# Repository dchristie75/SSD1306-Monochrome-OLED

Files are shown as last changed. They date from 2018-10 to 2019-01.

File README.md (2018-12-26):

# SSD1306 Monochrome OLED

## Build Instructions for Broadcom Devepolment Platform (Raspberry Pi 3B+) and SSD1306 OLED Display

### Table of Contents
1.  [Introduction](#introduction)
2.  [Bill of Materials](#bill-of-materials) 
3.  [Time Commitment](#time-commitment)
4.  [Mechanical Assembly](#mechanical-assembly)
5.  [PCB/Soldering](#pcb-soldering)
6.  [Power Up](#power-up)
7.  [Unit Testing](#unit-testing)
8.  [Production Testing](#production-testing)
9.  [Reproducible](#reproducible)

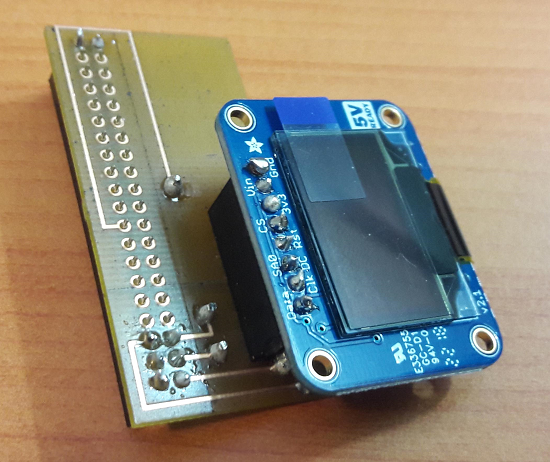
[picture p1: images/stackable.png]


### Introduction
The aim of this project is to integrate a sensor/effector with the Broadcom development platform, also known as the Raspberry Pi, in order to read/write data to the device. The sensor/effector chosen for this project is the SSD1306 OLED Monochrome Display from Adafruit. It is a 1" diagonal display that is made of 128x64 individual white OLED pixels that uses both SPI and I2C interfaces. Over the course of fifteen weeks, few necessary documentations were created, including the project proposal, a project breakdown schedule, and budget for the project. The necessary hardware components were also acquired, along with the required components to put everything together. A wiring circuit diagram was developed in [Fritzing](http://fritzing.org/home/) and was used to breadboard and test the sensor with the Broadcom development platform. Using that prototype, a custom PCB was designed and sent to the Prototype lab for etching. Headers were then soldered to the PCB for stacking and final assembly. The image above demonstrate the final stackable interface for the project. 

### Bill of Materials
To embark on the project, the necessary parts and components will need to acquired. Displayed below is the budget of the price breakdown for components used in the project. The spreadsheet version of the budget with links to the sources for the components can be found [here](https://github.com/dchristie75/SSD1306-Monochrome-OLED/blob/master/Documentation/Hardware_Production_Budget.xlsx).

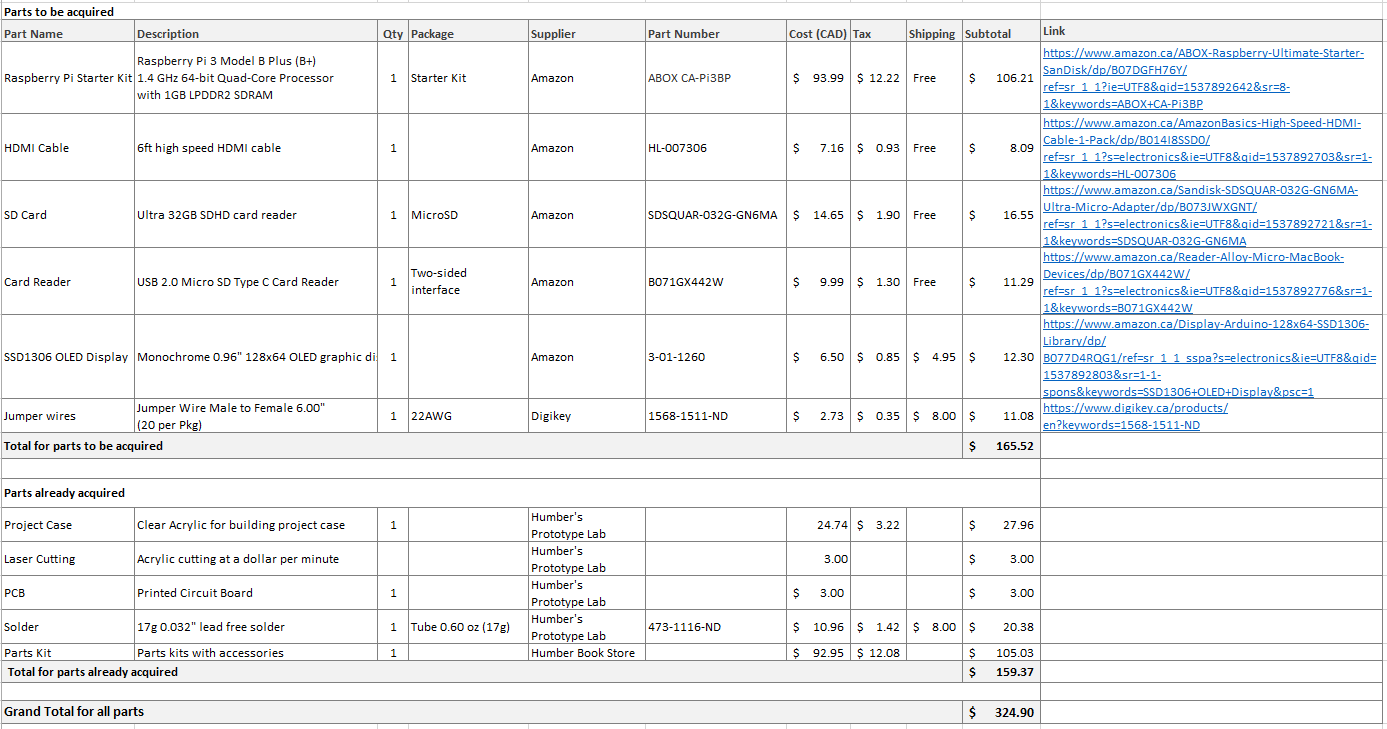
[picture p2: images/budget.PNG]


#### Listed below are some of the major components used in the project
SSD1306 OLED Monochrome 128x64 Display<br/>
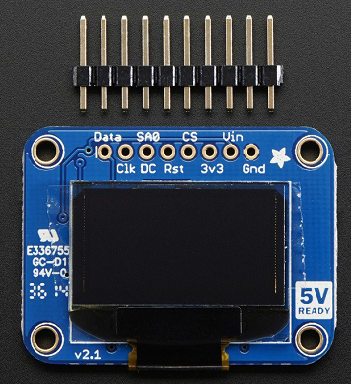
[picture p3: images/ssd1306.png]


Raspberry Pi Kit<br/>
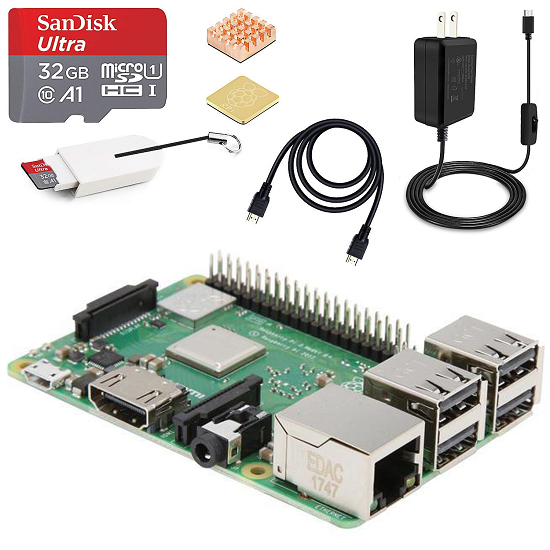
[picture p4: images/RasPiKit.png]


Components kit with stackable headers<br/>
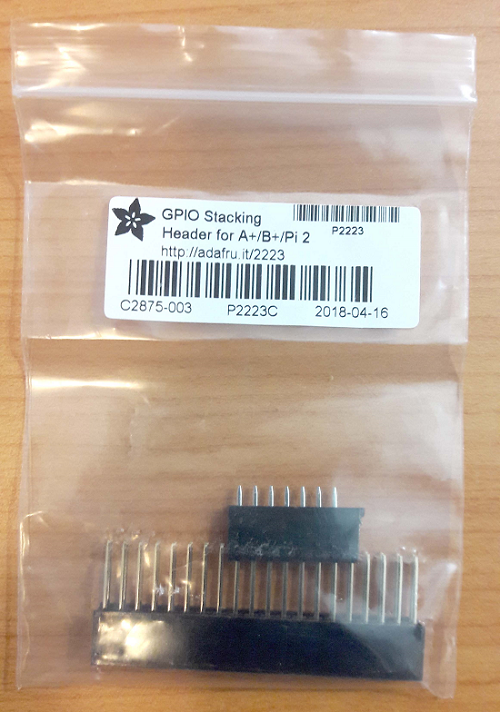
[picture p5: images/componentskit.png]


### Time Commitment
The entire project was done over the course of fifteen weeks, starting from selecting the OLED on September 4 to submitting the Build Instructions on December 11, 2018. However, to realistically build the project, a person could potentially use a weekend to complete it, assuming he has all the necessary components. Below is a breakdown of the project schedule.

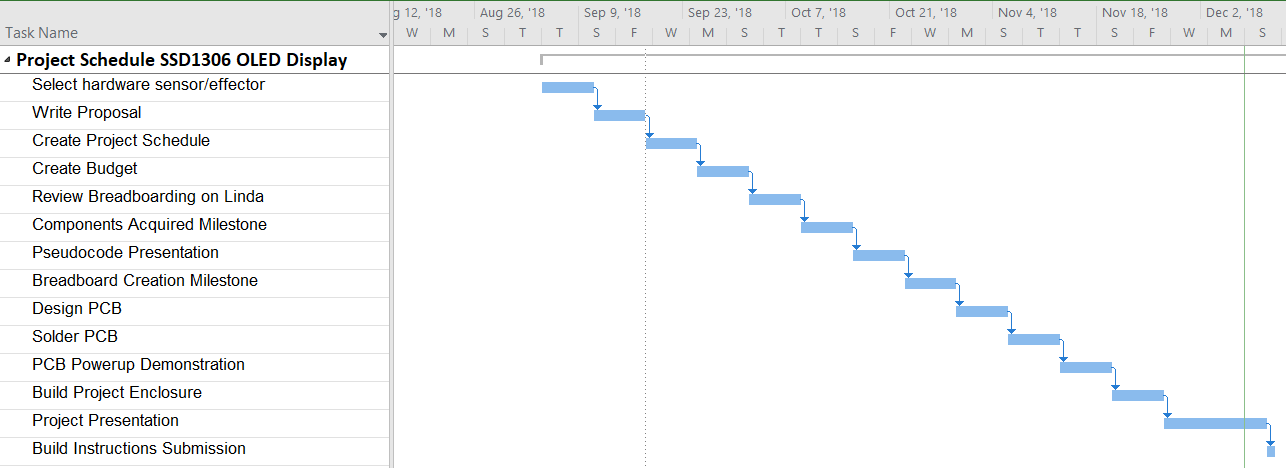
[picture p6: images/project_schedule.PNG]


### Mechanical Assembly
This step involves putting everything together. Hence, ensure the [8 pin header strip](https://github.com/dchristie75/SSD1306-Monochrome-OLED/blob/master/images/ssd1306.png) that comes with the OLED display is securely soldered to the device. Ensure the [PCB](https://github.com/dchristie75/SSD1306-Monochrome-OLED/blob/master/images/pcb.png) is designed in [Fritzing](http://fritzing.org/home/) and etched at the Prototype lab. Also, ensure the component [headers](https://github.com/dchristie75/SSD1306-Monochrome-OLED/blob/master/images/componentskit.png) are soldered onto the PCB. The enclosure should also be designed in [CorelDraw](https://www.coreldraw.com/en/product/coreldraw/?topNav=en) and sent to the Prototype lab for lazer cutting. The final CorelDraw design for the enclosure can be found [here](https://github.com/dchristie75/SSD1306-Monochrome-OLED/blob/master/Documentation/Pi2Case.cdr). After gathering all these components, now we are ready to assemble. Here are the steps involved: 

1. Mount the SSD1306 display to the PCB to create a stackable header<br/> 


2. Mount the stackable header to the Broadcom development platform GPIO port<br/>
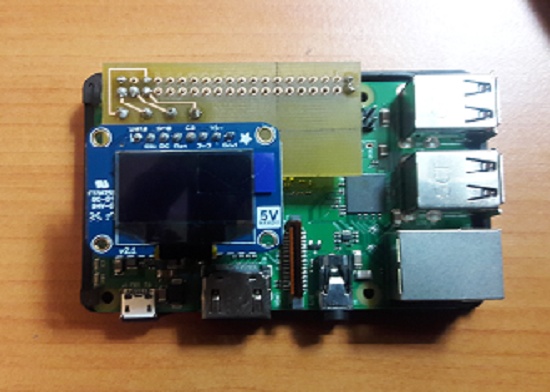
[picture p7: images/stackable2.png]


3. Install the Broadcom development platform with the stackable header in Acrylic enclosure<br/>
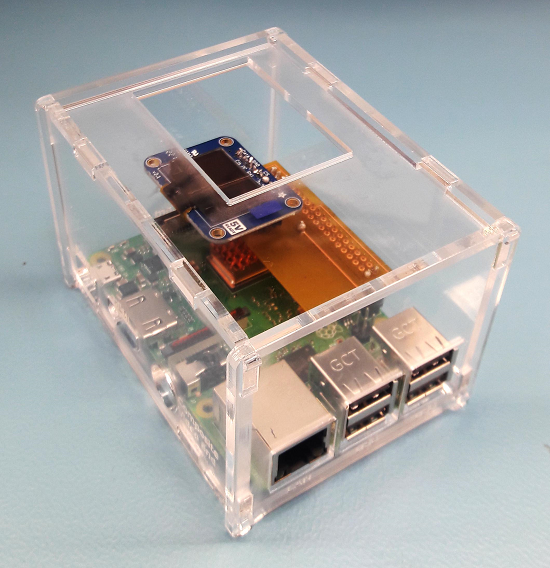
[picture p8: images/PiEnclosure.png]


### PCB Soldering
Soldering the components will take a little effort especially if you have never soldered before. Some good lesson on soldering can be found [here](https://www.youtube.com/watch?v=oqV2xU1fee8). Here are the steps in soldering all the components for the project:

1. Solder the two jumpers on the back of the OLED. Both must be soldered 'closed' for the I2C interface to work.

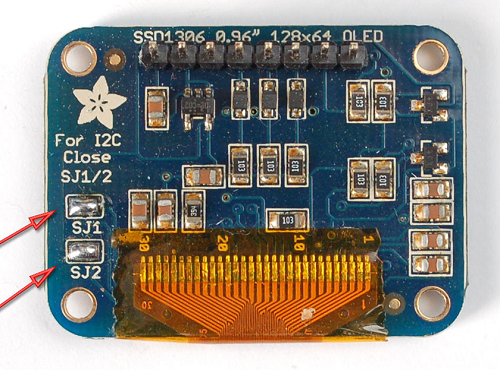
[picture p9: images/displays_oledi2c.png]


2. Solder the 8 pin header to the OLED display.

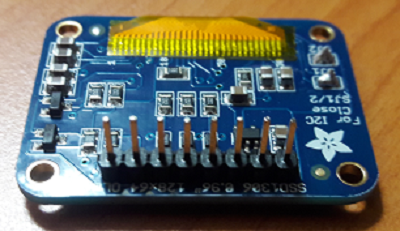
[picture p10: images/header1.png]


3. Design the initial breadboard layout for the PCB in Fritzing

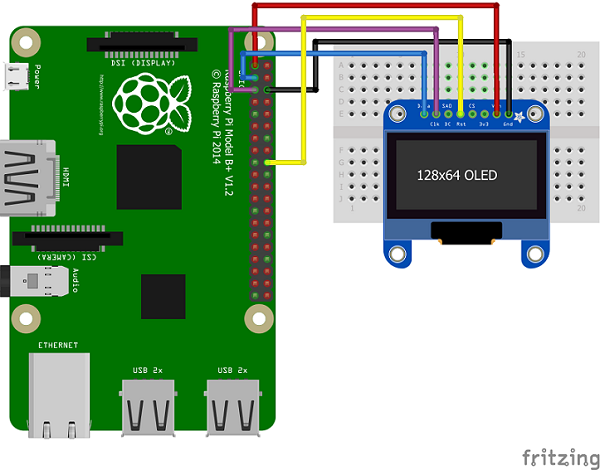
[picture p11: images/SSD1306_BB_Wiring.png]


4. The breadboard design layout will automatically generate a schematic diagram for the PCB design 

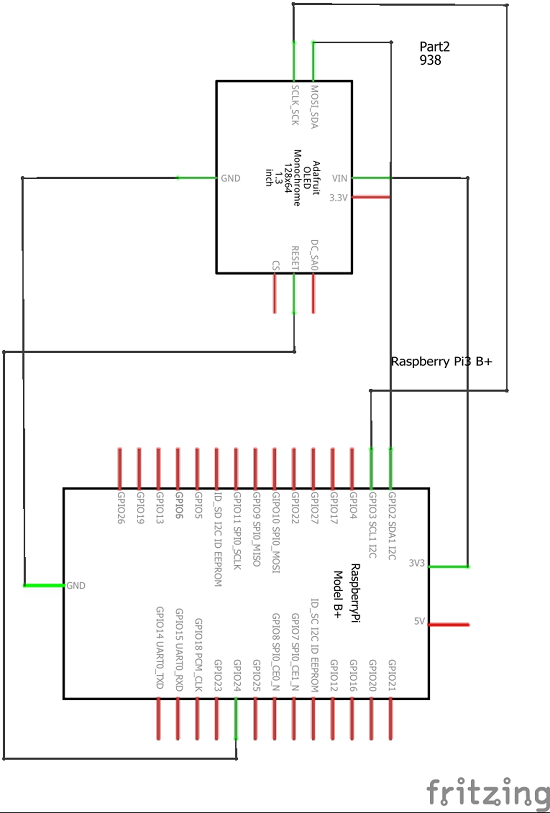
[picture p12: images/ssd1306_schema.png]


5. From the initial breadboard wiring design and resulting schema, design the actual PCB layout in Fritzing to send to production 

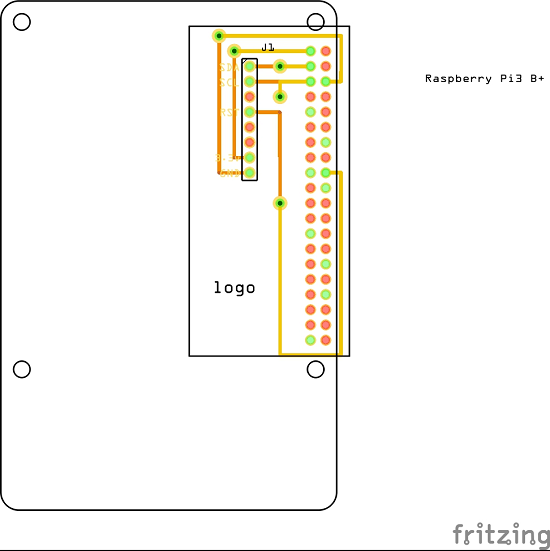
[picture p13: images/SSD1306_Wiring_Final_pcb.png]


6. Image of the resulting etched PCB after production 

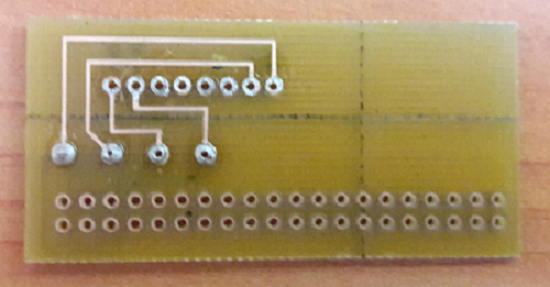
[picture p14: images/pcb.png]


7. Below is an image of the headers soldered to the PCB with OLED display mounted

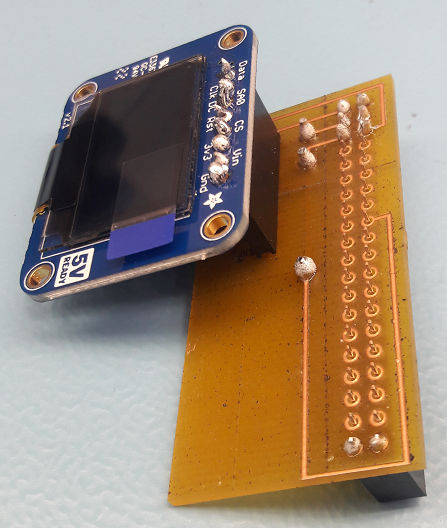
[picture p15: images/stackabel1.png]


 8. Below is the stackable header mounting to the Broadcom development platform



### Power Up
After connecting the OLED display with the Broadcom development platform through the I2C interface, the power up display looks like this:

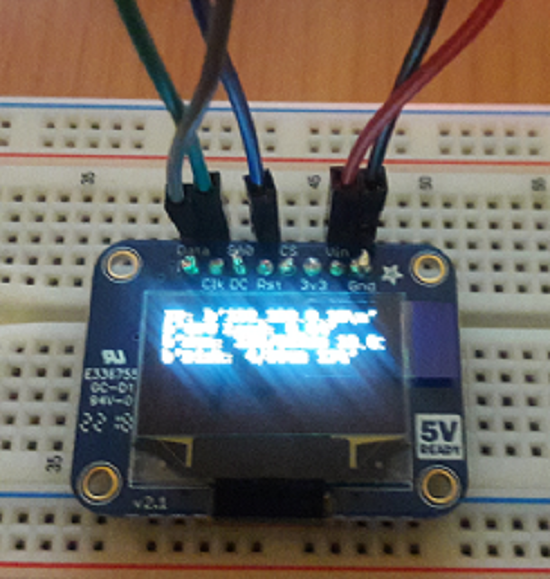
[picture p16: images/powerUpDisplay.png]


### Unit Testing
For the unit to be tested successfully, access to the internet is required as the SSD1306 Oled display will need the latest Python libraries and the Raspbian operating system will need to be up-to-date. Here are the steps involved in testing the unit:

1. Enable the I2C interface on the Raspberry pi. Run the following command and follow the steps:
  
       sudo raspi-config
   
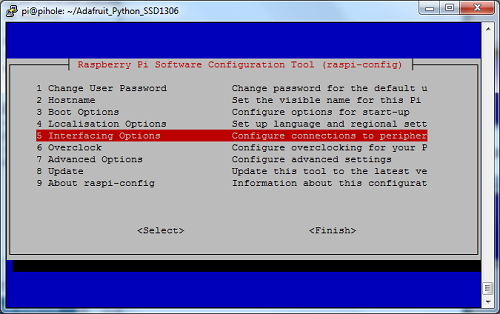
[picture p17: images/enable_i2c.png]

   
2. The second step is to ensure the I2C address is detected. To do that, execute the command: 

       sudo i2cdetect -y 1
    
The I2C address should look like this

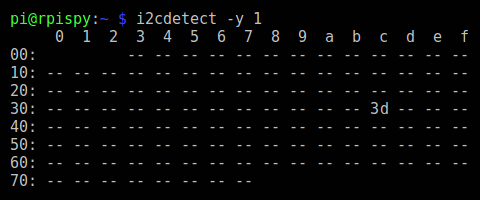
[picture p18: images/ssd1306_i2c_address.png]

    
3. Install the `RPi.GPIO` library by executing:

       sudo apt-get update
       sudo apt-get install build-essential python-dev python-pip
       sudo pip install RPi.GPIO `
     
4. Install the Python Imaging Library and smbus library by executing:
    
       sudo apt-get install python-imaging python-smbus
    
5. Download and install the SSD1306 python library code and examples, execute the following commands:

       sudo apt-get install git
       git clone https://github.com/adafruit/Adafruit_Python_SSD1306.git
       cd Adafruit_Python_SSD1306
       sudo python setup.py install `
    
6. Since we are using Raspbian operating system for this project, check the `/etc/modprobe.d/raspi-blacklist.conf` file and comment        `"blacklist i2c-bcm2708"` by running `sudo nano /etc/modprobe.d/raspi-blacklist.conf` and adding a `#` (if its not there).     

7. Navigate to the `Adafruit_Python_SSD1306/examples` subdirectory. You will find python scripts which demonstrate the usage of the        library. For example, open `shapes.py`. Comment `SSD1306_128_32` class and uncomment `SSD1306_128_64` class since we are using the      128x64 display. The default address used for the Python libraries is `3C`. However, the SSD1036 display uses the address `3D`. So add    the the code `i2c_bus_address=3D` after `rst=RST`. So the the class should look like this:

       disp = Adafruit_SSD1306.SSD1306_128_64(rst=RST, i2c_bus_address=3D) 
    
   You can run the code by executing this command in the examples directory: 
   
       sudo python shapes.py

   You should see something like this: 

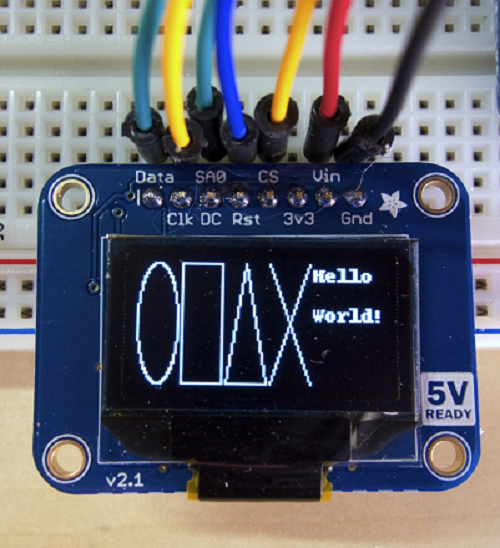
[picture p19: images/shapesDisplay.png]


   You have successfully integrated the Broadcom development platform with the SSD1306 Monochrome OLED display!

### Production Testing
Here is the display of the final product with all the components integrated. 



### Reproducible
Following this build instructions carefully will ensure the project is reproducible.

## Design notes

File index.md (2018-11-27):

SSD1306_OLED_Sensor
===============
### November 27th, 2018 (Week 13)
As indicated in my [project schedule](https://github.com/dchristie75/SSD1306-Monochrome-OLED/blob/master/Documentation/Project_Schedule.mpp), today is the project presentation milestone. This week being the presentation, I didn't have much to do in terms of hardware setup and configuration, since all harware setup and enclosure fitting was done in previous weeks. So abviously my budget is unchanged and my schedule is on track. [Here](https://github.com/dchristie75/SSD1306-Monochrome-OLED/blob/master/Documentation/CENG317%20Presentation.pptx) is a link to the presenation.   

### November 20th, 2018 (Week 12)

Today the enclosure for the Broadcom development platform is due, as outlined in my [project schedule](https://github.com/dchristie75/SSD1306-Monochrome-OLED/blob/master/Documentation/Project_Schedule.mpp). After acquiring the CorelDraw design files, I worked hard to edit these files to suite my project design. [Here](https://github.com/dchristie75/SSD1306-Monochrome-OLED/blob/master/Documentation/Pi2Case.cdr) is the edited file to suite my Broadcom development platform and stackable header with sensor. I am satisfied with the finished product as the enclosure is tall enough to house my sensor while providing enough protection for its contents. [Here](https://github.com/dchristie75/SSD1306-Monochrome-OLED/blob/master/Index_src/PiCase.jpg) is a view of the finish product.

As I complete this milestone, I am pleased to report that the project remains on track. My [financial status](https://github.com/dchristie75/SSD1306-Monochrome-OLED/blob/master/Documentation/Hardware_Production_Budget.xlsx) remains unchanged as the acrylic material for the case and the laser cutting was done through the prototype lab.

### November 13th, 2018 (Week 11)

As outlined in my [project schedule](https://github.com/dchristie75/SSD1306-Monochrome-OLED/blob/master/Documentation/Project_Schedule.mpp) today is the power-up demonstration milestone. This week I was busy trying to configure my SSD1306 OLED monochrome display for text and image display. I ran into a few challenges in relation to the I2C interface—the interface we are required to use for this project. The problem is: the default address of the hardware was different from the one referencing by all the Python libraries. This was a challenge because no communication can occur without the correct address being configured. Hence, great effort went into figuring out how to configure the address to be compatible with the Python libraries, along with all the other dependencies. After resolving that issue, communication was established but only random dots were being displayed. Again to resolve the issue, I consulted many [online]( https://www.raspberrypi-spy.co.uk/2018/04/i2c-oled-display-module-with-raspberry-pi/#comment-227572) [references]( http://hallard.me/adafruit-ssd1306-oled-display-driver-for-raspberry-pi/) and [forums](https://forums.adafruit.com/viewtopic.php?f=57&t=132871&p=659887&hilit=ssd1306+OLED+raspberry+pi#p659887). On Nov. 12 however, I finally figured out that for this OLED display model, the RST line must be connected to the GPIO24 on the Raspberry Pi to work; along with modifying the /etc/modules, /etc/modprobe.d/raspi-blacklist.conf, and the .py files in the examples folder. The necessary wiring adjustment was made to the PCB [Fritzing](https://github.com/dchristie75/SSD1306-Monochrome-OLED/blob/master/Documentation/SSD1306_Wiring_Final.fzz) design and [Gerber](https://github.com/dchristie75/SSD1306-Monochrome-OLED/blob/master/Documentation/SSD1306_Gerber_Files.rar) files sent to the prototype lab for re-printing. Because of the time it took to reprint the PCB, I did not receive it in time for an in-class demonstration with the Raspberry PI. Hence, the demonstration was done with the breadboard. This hardware problem gave me an opportunity to do comprehensive research and collaboration with others to find a solution. With the completion of this milestone, I am within [schedule](https://github.com/dchristie75/SSD1306-Monochrome-OLED/blob/master/Documentation/Project_Schedule.mpp) of the project’s completion. Since a reproduction of the PCB was needed, an additional cost of [$4.90](https://www.seeedstudio.com/fusion.html) was added to the overall budget. Here is an [image](https://github.com/dchristie75/SSD1306-Monochrome-OLED/blob/master/Index_src/20181113_000239.jpg) the preliminary final display setup.

### November 6th, 2018 (Week 10)

As outlined in my [project schedule](https://github.com/dchristie75/SSD1306-Monochrome-OLED/blob/master/Documentation/Project_Schedule.mpp), today is the PCB soldered milestone. With the completion of this milestone, I am within schedule with respect to the project completion. During the past week, I worked on creating the layout for PCB wiring and design in Fritzing. I aim to connect the SSD1306 OLED Monochrome display with the Raspberry Pi, and the sockets to enable this process were incorporated into the PCB design. I found [a site that offered hepful](https://www.raspberrypi-spy.co.uk/2018/04/i2c-oled-display-module-with-raspberry-pi/) information regarding connecting the pins and configuring the I2C interface, along with importing the relevant Python libraries. As outlined in my previous post, there was a problem detecting the address of the SSD1306 display. However, collaboration with Kelly and Vlad from the Prototype Lab helped to resolve the issue. That issue gave me an opportunity to delve deeper into troubleshooting hardware while improving my soldering skills. 

My [Budget](https://github.com/dchristie75/SSD1306-Monochrome-OLED/blob/master/Documentation/Hardware_Production_Budget.xlsx) included headers, but these were not bought with the other products. Therefore, these [headers](https://www.digikey.ca/product-detail/en/sullins-connector-solutions/PPTC081LFBN-RC/S7006-ND/810147) were had from the Prototype Lab with a collective value of [$5.06](https://www.digikey.ca/product-detail/en/adafruit-industries-llc/2223/1528-1385-ND/5629433). My PCB design was done and Gerber files sent to the Protoype Lab for production without any problems. Here is an image of the [final PCB](https://github.com/dchristie75/SSD1306-Monochrome-OLED/blob/master/images/pcb.jpg) with soldered headers connected to the Rapberry pi and the [Fritzing files](https://github.com/dchristie75/SSD1306-Monochrome-OLED/blob/master/Documentation/SSD1306_Wiring_Final.fzz) that they result from. Additional images can be found [here](https://github.com/dchristie75/SSD1306-Monochrome-OLED/tree/master/Index_src).

### October 30th, 2018 (Week 10)

This blog entry is to give a progress update on my hardware project. As indicated in my [project schedule](https://github.com/dchristie75/SSD1306-Monochrome-OLED/blob/master/Documentation/Project_Schedule.mpp) this week is the PCB designed milestone. Last week there were some issues detecting the sensor's I2C address. However, after visiting Kelly and Vlad in the prototype lab during the course of the week we managed to find the problem and correct it. It turns out that contacts on the back of the device must be soldered close in order to enable I2C, since the device is default to the SPI interface. So with that issue resolved, at this time I am on track and within budget of my project. The [PCB schema](https://github.com/dchristie75/SSD1306-Monochrome-OLED/blob/master/Index_src/SSD1306_Wiring_Final_pcb.jpg) was designed and sent to the prototype lab for etching. I do not need to purchase any further part for the project so no additional cost is added to my original budget. Moving on to the soldering porting of the project next week.

### October 23rd, 2018 (Week 8)

This blog entry is to give an update into my progress on my hardware sensor. At this point in the semester (Week 8), I am on schedule. However, I connected the SSD1306 OLED sensor using I2C connection but it did not work. I tried various times using various appropriate pin connectors but it still didn't work. The professor suggested tried connecting using SPI instead of I2C; or in case that didn't work, tried using an Arduino to see if that works. During the course of this week I will contact Vlad or Kelly at the prototype lab to figure out this problem. So this is a minor, or possibly a major setback in my progress. It will also put me in a negative financial status since I will have to repurchase the OLED sensor in the worst case scenario.

Image of what I have so far:
[Hardware Connection](hardware.png)

### October 16th, 2018 (Week 7)

This week, as outline is my [project schedule](https://github.com/dchristie75/SSD1306-Monochrome-OLED/blob/master/Documentation/Project_Schedule.mpp), the submission of the Pseudocode assignment is due. I was able to meet with the two first year students and successfully complete the pesudocde assignment. 

### October 9th, 2018 (Week 6) 

### October 2nd, 2018 (Week 5)

This week we submit a Proof of purchase. 

### Item(s) to be delivered
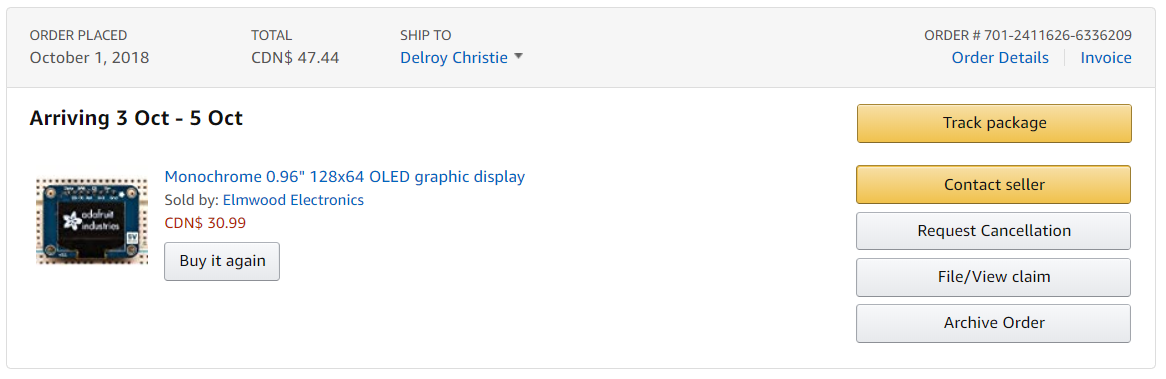
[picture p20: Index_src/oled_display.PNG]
Item(s) to be delivered this week


### Item(s) already delivered
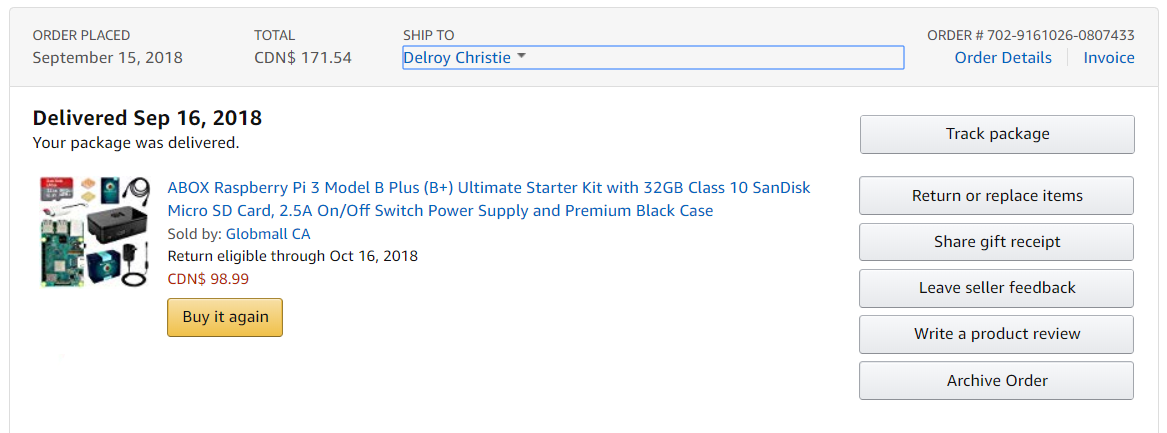
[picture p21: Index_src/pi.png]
Item(s) already delivered to recipient


### September 25th, 2018 (Week 4)

Created [budget document](Documentation/Hardware_Production_Budget.xlsx)

### September 18th, 2018 (Week 3)

Created [Project Schedule](Documentation/Project_Schedule.mpp)

### September 11th, 2018 (Week 2)

Created [Proposal Content](Documentation/Proposal_Content.xlsx)

Created the GitHub repository

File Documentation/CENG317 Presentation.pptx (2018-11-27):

## SSD1306 Monochrome OLED DISPLAY

Presented by: Delroy Christie

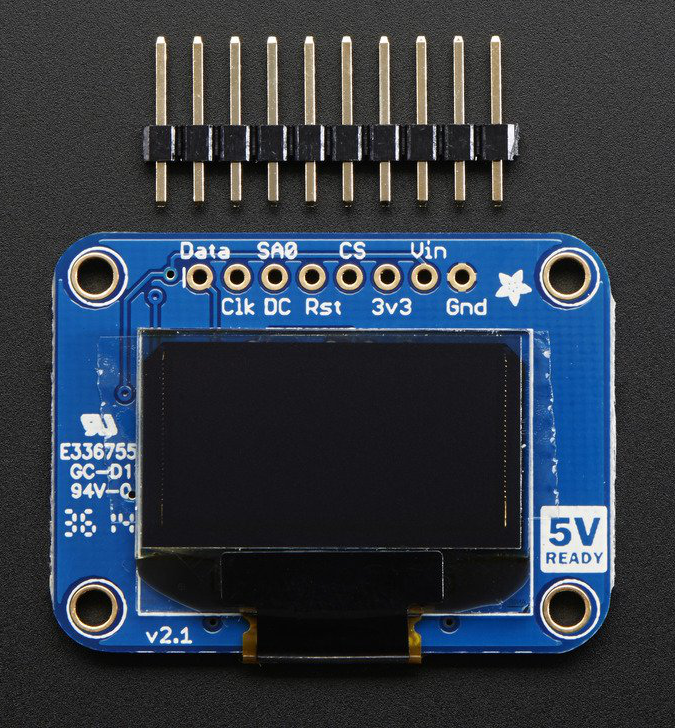
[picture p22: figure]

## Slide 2

INTRODUCTION

Proposal
As a student in the Computer Engineering Technology program, my goal was to integrating the knowledge and skills I have learned from our program into this IoT themed project.
So the aim of my project was to connect my SSD1306 Monochrome OLED display sensor/effector to the Broadcom development platform (AKA Raspberry Pi) to display texts and images pulled from an external source. This is a small part of the broader objective for next semester, which is to integrate sensor with the other two sensors from my group (accelerometer and capacitive touch sensor) to create a real world IoT device which connects to an external database through an android mobile application which we developed.
The internet connected hardware will include a custom PCB with the sensors for measuring distances and touch, and the database will store the data generated from the sensors.
Thus far, I have worked thirteen weeks on the project, culminating into today’s presentation.

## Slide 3

budget

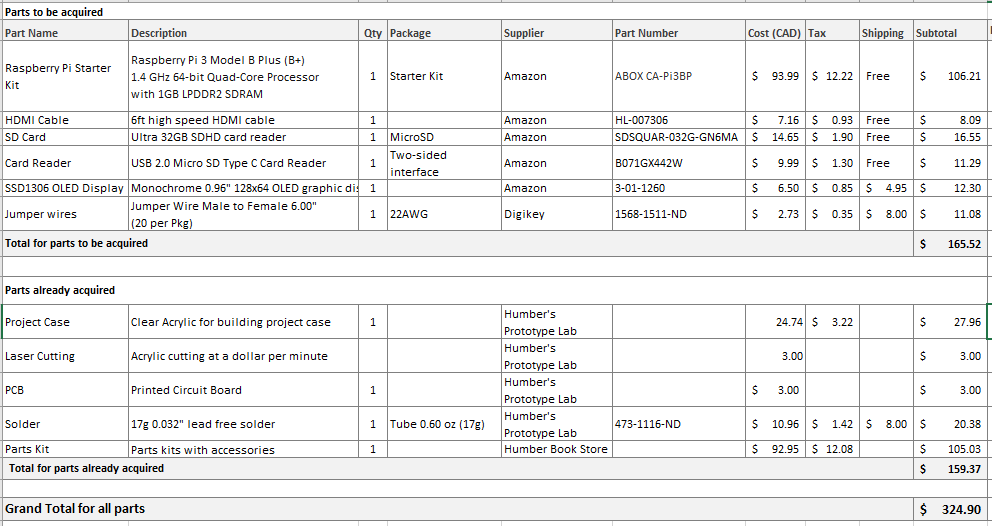
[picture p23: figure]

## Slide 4

schedule

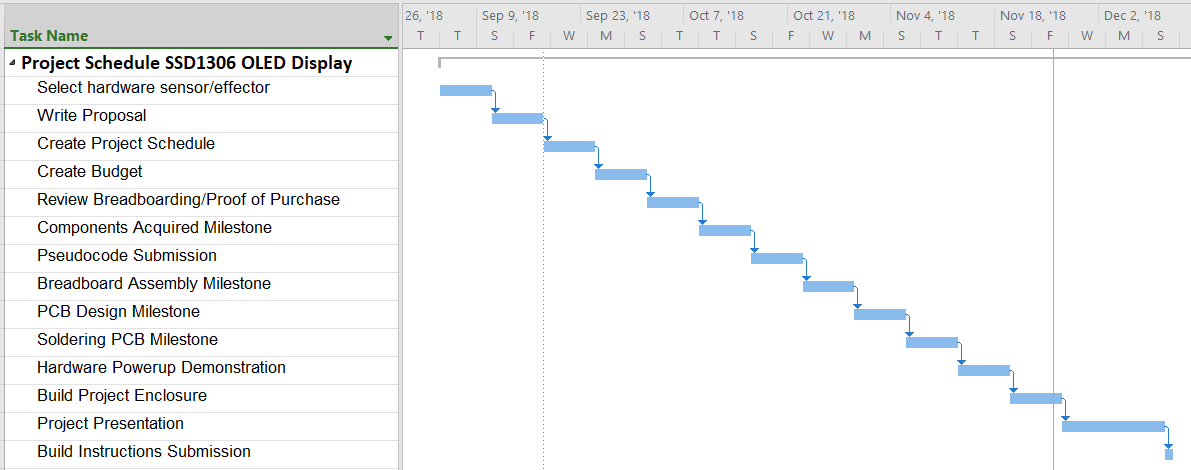
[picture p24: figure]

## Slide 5

images

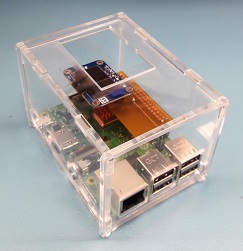
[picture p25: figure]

Project Enclosure

SSD1306 I2C Address

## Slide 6

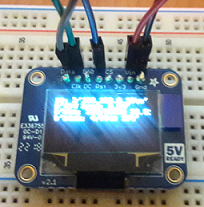
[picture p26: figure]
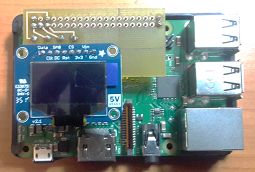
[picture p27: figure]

Writing to SSD1306 OLED Broadcom Development Platform with Stackable Header

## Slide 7

knowledge utilized from previous courses

In order to have completed this project, the knowledge garnered from previous courses was applied. The courses that were a direct contributing factor to the successful completion of this project are:

TECH 150 Electronic devices and circuits
TECH 153 Technical C
WRIT 220 Technical Workplace Writing Skills
CENG 209 Micro Assembly Programming
CENG 215 Digital And Interfacing Systems
CENG 216 Introduction to Software Engineering
CENG 251 UNIX Internals
CENG 252 Embedded Systems
CENG 317 Hardware Production Technology

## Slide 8

Thank You

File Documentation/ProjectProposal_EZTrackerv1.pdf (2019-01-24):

January 17, 2019

Proposal for the development of EZ Tracker
Prepared by Ryan Maynard, Jonas Gamao, Delroy Christie Computer Engineering Technology Student
https://github.com/YamiYukiSenpai/EZTracker

Executive Summary
As a student in the Computer Engineering Technology program, I will be integrating the knowledge and skills I have learned from our program into this Internet of Things themed capstone project. This proposal requests the approval to build the hardware portion that will connect to a database as well as to a mobile device application. The internet connected hardware will include a custom PCB with the following sensors and actuators: SSD1306 Monochrome OLED, MPR121 12-Point Capacitive Touch Sensor, and LSM303 Accelerometer & Magnetometer. The database will store: Step Count, Calories, Weight, Age, Heigh, Date of Birth, Name, E-mail. The mobile device functionality will include: View calories burned, steps, and direction through the SSD1306 OLED. Toggle start/stop/pause with the MPR121 Touch Sensor. Collect and interpret data with LSM303 Accelerometer & Magnetometer. This will be further detailed in the mobile application proposal. I will be collaborating with the following company/department: School of Media Studies & Information Technology, and School of Hospitality Recreation and Tourism. This semester, our group will consist of the following students, who are also building similar hardware this term and working on the mobile application with me: Ryan Maynard, Jonas Gamao, Delroy Christie. The hardware will be completed in CENG 317 Hardware Production Techniques independently and the application will be completed in CENG 319 Software Project. These will be integrated together in the subsequent term in CENG 355 Computer Systems Project as a member of a 2 or 3 student group.

Background
The problem solved by this project is Simplfying the current pedometer for the aging generation looking to get healthy. Most older users are turned off by complex devices and UIs. Being able to monitor their own health by implementing a simple and user-friendly interface can lead to a more active lifestyle. A bit of background about this topic is that Pedometers/wearable/portable technology is used everywhere. With the baby boomers becoming an aging population, and with health concerns on the rise, this easy to use system can promote a healthier lifestyle with the added ease of use. By using IoT/Cloud software, users can track their usage and compare it over days/weeks/months to ensure they are getting the exercise needed. Existing products on the market include [1]. I have searched for prior art via Humber’s IEEE subscription selecting “My Subscribed Content” [2] and have found and read [5][6][7] which provides insight into similar efforts.
In the Computer Engineering Technology program we have learned about the following topics from the respective relevant courses:
- Java Docs from CENG 212 Programming Techniques In Java,
- Construction of circuits from CENG 215 Digital And Interfacing Systems,
- Rapid application development and Gantt charts from CENG 216 Intro to Software Engineering,
- Micro computing from CENG 252 Embedded Systems,
- SQL from CENG 254 Database With Java,
- Web access of databases from CENG 256 Internet Scripting; and,
- Wireless protocols such as 802.11 from TECH152 Telecom Networks.
This knowledge and skill set will enable me to build the subsystems and integrate them together as my capstone project.

Methodology
This proposal is assigned in the first week of class and is due at the beginning of class in the second week of the fall semester. My coursework will focus on the first two of the 3 phases of this project:
Phase 1 Hardware build.
Phase 2 System integration.
Phase 3 Demonstration to future employers.

Phase 1 Hardware build
The hardware build will be completed in the fall term. It will fit within the CENG Project maximum dimensions of 12 13/16" x 6" x 2 7/8" (32.5cm x 15.25cm x 7.25cm) which represents the space below the tray in the parts kit. The highest AC voltage that will be used is 16Vrms from a wall adaptor from which +/-15V or as high as 45 VDC can be obtained. Maximum power consumption will be 20 Watts.

Phase 2 System integration
The system integration will be completed in the fall term.
Phase 3 Demonstration to future employers

This project will showcase the knowledge and skills that I have learned to potential employers.

The brief description below provides rough effort and non-labour estimates respectively for each phase. A Gantt chart will be added by week 3 to provide more project schedule details and a more complete budget will be added by week 4. It is important to start tasks as soon as possible to be able to meet deadlines.
Stacking Headers, Case Revisions

Concluding remarks
This proposal presents a plan for providing an IoT solution for A user friendly, Cloud/IoT based pedometer to monitor health for the technologically inexperienced aging population. This is an opportunity to integrate the knowledge and skills developed in our program to create a collaborative IoT capstone project demonstrating my ability to learn how to support projects such as the initiative described by [5][6][7]. I request approval of this project.

References
[1] KNOW YOURSELF TO IMPROVE YOURSELF. (n.d.). Retrieved from https://www.fitbit.com/en-ca/home
[2] Wulff, A. (2017, September 24). Capacitive Touch Keyboard Extension with Leonardo. Retrieved from https://www.hackster.io/AlexWulff/capacitive-touch-keyboard-extension-with-leonardo-13a387
[3] SSD1306 I2C OLED – Muybridge Animation. (2016). Retrieved from https://forum.arduino.cc/index.php?topic=375985.0
[4] Institute of Electrical and Electronics Engineers. (2015, August 28). IEEE Xplore Digital Library [Online]. Available: https://ieeexplore.ieee.org/search/advsearch.jsp
[5] Genovese, V., Mannini, A., & Sabatini, A. M. (2017). A Smartwatch Step Counter for Slow and Intermittent Ambulation. IEEE Access, 5, 13028-13037. doi:10.1109/access.2017.2702066
[6] Smith, J. T., Obrien, B., Lee, Y., Bawolek, E. J., & Christen, J. B. (2014). Application of Flexible OLED Display Technology for Electro-Optical Stimulation and/or Silencing of Neural Activity. Journal of Display Technology, 10(6), 514-520. doi:10.1109/jdt.2014.2308436
[7] Ruan, J., Chao, P. C., & Chen, W. (2010). A multi-touch interface circuit for a large-sized capacitive touch panel. 2010 IEEE Sensors. doi:10.1109/icsens.2010.5689881

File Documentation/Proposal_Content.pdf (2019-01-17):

Submission Date | 11-9-2018
Project Name | SSD 1306 Monochrome OLED Graphic Display
Student Name | Delroy Christie
Project repository | https://github.com/dchristie75/SSD1306-Monochrome-OLED
SensorEffector Choice | SSD1306 Monochrome OLED
The database will store | Texts, images, and animated graphics
The mobile device functionality will include | A capacitive touch interface that allows users to input data, stores the data to a remote database, and displays results on the OLED display for viewing.
I will be collaborating with the following company/department | Humber College School of Applied Technology
My group in the winter semester will include | Ryan Maynard, Jonas Gamao
50 word problem statement | LEDs have been the display of choice for both small and larger devices for many years. However, there some limitations to their usage in terms of display. The SSD1306 monochrome OLED seeks to solve those limitations by working with the Raspberry Pi to create animated graphics and monochrome bitmap images for individuals that require more flexibly displays. The device consumes very little power compared to its counterparts and offers improved response time and quality of output.

100 words of background

The LED is currently the display of choice in small and larger devices. Regular LEDs often form the digits on digital clocks and many other electronic applications. OLEDs, on the other hand, offer many advantages over regular LEDs. The plastic, organic layers of the 1306 Monochrome 3D OLED display are thinner, lighter and more flexible than the crystalline layers in a typical LED. Because the light-emitting layers of this display is lighter, the substrate can be flexible instead of rigid. And since the display makes its own light, no backlight is required. This reduces the OLED power consumption, making it more efficient with a higher display contrast. The OLED therefore offers a crisper display and operates at wider ranging temperatures and wider viewing ranges.

Current product APA citation | Devara, K., Ramadhanty, S., & Abuzairi, T. (2018, February 13). Design of wearable health monitoring device. Retrieved from https://aip.scitation.org/doi/pdf/10.1063/1.5023992?class=pdf
Existing research IEEE paper APA citation | Smith, J. T., Obrien, B., Lee, Y., Bawolek, E. J., Christen, J. B. (2014). Application of Flexible OLED Display Technology for Electro-Optical Stimulation and/or Silencing of Neural Activity. Journal of Display Technology, 10(6), 514-520. doi:10.1109/jdt.2014.2308436
Brief description of planned purchases | Purchases will include a Raspberry Pi, 32 GB SD card, heat sinks, SSD1306 OLED Sensor, bread board, GPIO connectors, and jumper wires.
Solution description | Monochrome displays generally display simple text or numbers. Hence, organizations are generally limited in what they can display using regular LEDs. The SSD1306 Monochrome OLED display will solve that problem by not only displaying text and numbers, but also high contrast bitmap images and animated graphics.

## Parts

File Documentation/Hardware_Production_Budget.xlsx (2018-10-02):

Name: Delroy Christie
Parts to be acquired
Part Name | Description | Qty | Package | Supplier | Part Number | Cost (CAD) | Tax | Shipping | Subtotal | Link
Raspberry Pi Starter Kit | Raspberry Pi 3 Model B Plus (B+) 1.4 GHz 64-bit Quad-Core Processor with 1GB LPDDR2 SDRAM | 1 | Starter Kit | Amazon | ABOX CA-Pi3BP | $93.99 | $12.22 | Free | $106.21 | https://www.amazon.ca/ABOX-Raspberry-Ultimate-Starter-SanDisk/dp/B07DGFH76Y/ ref=sr_1_1?ie=UTF8&qid=1537892642&sr=8-1&keywords=ABOX+CA-Pi3BP
HDMI Cable | 6ft high speed HDMI cable | 1 |  | Amazon | HL-007306 | $7.16 | $0.93 | Free | $8.09 | https://www.amazon.ca/AmazonBasics-High-Speed-HDMI-Cable-1-Pack/dp/B014I8SSD0/ ref=sr_1_1?s=electronics&ie=UTF8&qid=1537892703&sr=1-1&keywords=HL-007306
SD Card | Ultra 32GB SDHD card reader | 1 | MicroSD | Amazon | SDSQUAR-032G-GN6MA | $14.65 | $1.90 | Free | $16.55 | https://www.amazon.ca/Sandisk-SDSQUAR-032G-GN6MA-Ultra-Micro-Adapter/dp/B073JWXGNT/ ref=sr_1_1?s=electronics&ie=UTF8&qid=1537892721&sr=1-1&keywords=SDSQUAR-032G-GN6MA
Card Reader | USB 2.0 Micro SD Type C Card Reader | 1 | Two-sided interface | Amazon | B071GX442W | $9.99 | $1.30 | Free | $11.29 | https://www.amazon.ca/Reader-Alloy-Micro-MacBook-Devices/dp/B071GX442W/ ref=sr_1_1?s=electronics&ie=UTF8&qid=1537892776&sr=1-1&keywords=B071GX442W
SSD1306 OLED Display | Monochrome 0.96" 128x64 OLED graphic display | 1 |  | Amazon | 3-01-1260 | $6.50 | $0.84 | $4.95 | $12.29 | https://www.amazon.ca/Display-Arduino-128x64-SSD1306-Library/dp/ B077D4RQG1/ref=sr_1_1_sspa?s=electronics&ie=UTF8&qid=1537892803&sr=1-1-spons&keywords=SSD1306+OLED+Display&psc=1
Jumper wires | Jumper Wire Male to Female 6.00" (20 per Pkg) | 1 | 22AWG | Digikey | 1568-1511-ND | $2.73 | $0.35 | $8.00 | $11.08 | https://www.digikey.ca/products/ en?keywords=1568-1511-ND (https://www.digikey.ca/products/en?keywords=1568-1511-ND)
Total for parts to be acquired |  |  |  |  |  |  |  |  | $165.52
Parts already acquired
Project Case | Clear Acrylic for building project case | 1 |  | Humber's Prototype Lab |  | 24.74 | $3.22 |  | $27.96
Laser Cutting | Acrylic cutting at a dollar per minute |  |  | Humber's Prototype Lab |  | 3.00 |  |  | $3.00
PCB | Printed Circuit Board | 1 |  | Humber's Prototype Lab |  | $3.00 |  |  | $3.00
Solder | 17g 0.032" lead free solder | 1 | Tube 0.60 oz (17g) | Humber's Prototype Lab | 473-1116-ND | $10.96 | $1.42 | $8.00 | $20.38
Parts Kit | Parts kits with accessories | 1 |  | Humber Book Store |  | $92.95 | $12.08 |  | $105.03
Total for parts already acquired |  |  |  |  |  |  |  |  | $159.37
Grand Total for all parts |  |  |  |  |  |  |  |  | $324.90
